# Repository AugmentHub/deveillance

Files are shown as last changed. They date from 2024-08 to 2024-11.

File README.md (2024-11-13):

# Deveillance Devices
We started this project as we have seen an increase in potentially privacy invading devices, such as wearable AI necklace, AR glasses that can take pictures of you, and more. Throughout the 2024 Augmentation Residency, we - Aida Baradari, Treyden Chiaravalloti, and Nasibe Nur Dundar - were thinking about ways of building what we coin "deveillance" technologies. 

**Deveillance** means off-watching, and we define deveillance technologies as technologies that give the power to the individual as to what data is collected and what is not collected. This can take the form of digital data and data potentially collected in the real world. This is, fundamentally, to build the use of these technologies for good and protective measures rather than for malicious intentions. 

There is still a lot of work to be done and we need more engineers tackling the problems of data collection in all realms. We started with Audio but this is a hub for everyone to contribute to a better design of deveillance devices. 

## Audio
Audio Jammers have existed for a while now but has been increasingly difficult to find affordable ones or even good, structured tutorials of how to make your own. This is how we built an audio jammer and how this works.

We are using a motor driver - more specifically the H-Bridge - L298N in order to generate a square wave signal. We formally tried using a signal generator with an amplifier but found it more difficult to get a non-noisy signal. 
The generated square-wave signal is based on the input voltage, for which you can use a power supply for now but we will eventually add batteries that are high enough (to get a good power output, we are currently using the H-Bridge that go up to 30V and 2A) but when we make it more wearable and you want to use it on your shelf, you may want to use a DC-DC Converter, upping the voltage of a generic LiPo battery. 

We are explaining how the Physics behind this works and then also how to make it yourself. 

### Wait, but why does it work? 
In a very simple way of explaining, without needing much physics background: Microphones have diaphragms. When sound hits that diaphragm, it vibrates it, and that movement creates electrical signals (in an abstract way of explaining it). 
Now, sound has different frequencies. We can hear a certain range of frequencies (20Hz to 20kHz) but below or higher than that humans can generally not hear. If you are close enough to our hearing frequency, however, the diaphragm of the microphone can sometimes pick it up. 
And because of this, your voice will be overridden. It cannot be filtered out. 

### Make It Yourself
- [Transducers](https://en.wikipedia.org/wiki/Transducer): For the bigger version, we are currently using the [2223-CUSA-T601-150-2400-TH-ND](https://www.digikey.com/en/products/detail/same-sky-formerly-cui-devices/CUSA-T601-150-2400-TH/16579211). 
- Arduino Nano (or any other Arduino / microcontroller device)

**Putting Things Together**
Here is how we are currently wiring things together (though the topology is very likely to change) :
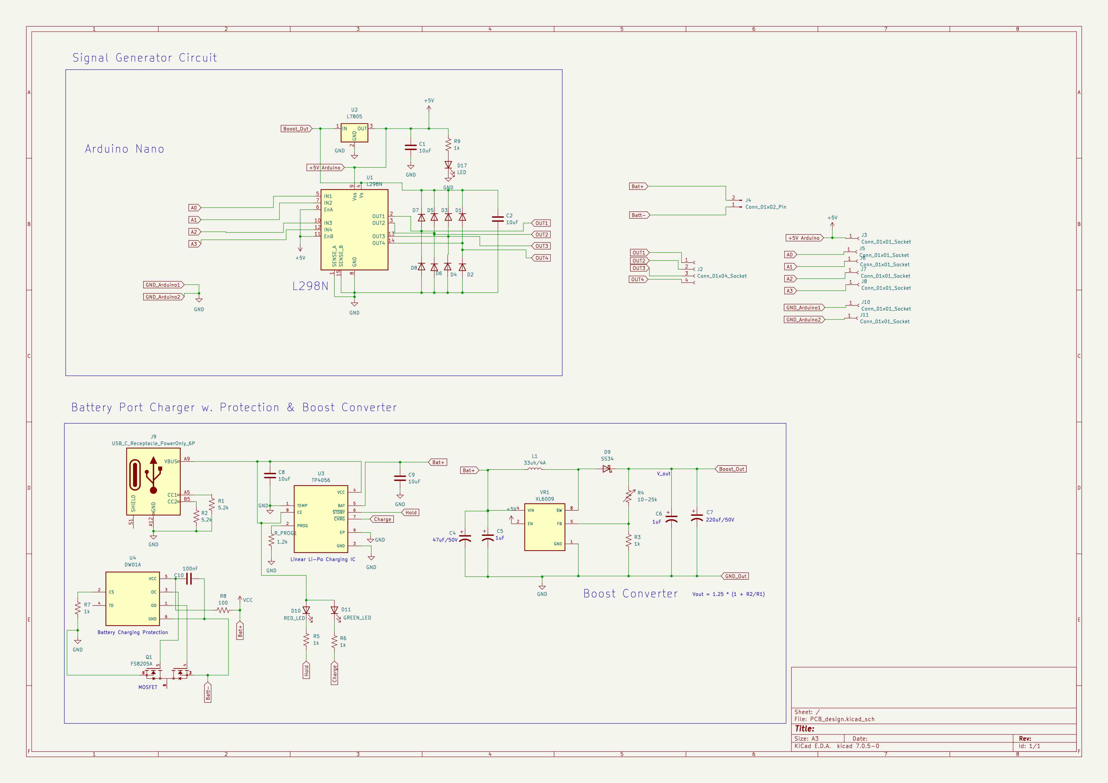
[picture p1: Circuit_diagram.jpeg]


### PCB Design 
Within this directory you will also find a PCB design with the L298N chip on board, battery charging circuit and more included. 
The data parts we are using are the following: 

- TP4056: 1A Standalone Linear Li-Ion Battery Charger with Thermal Regulation. This is for charging our battery and is connected to a USB port. You can find the datasheet [here](https://dlnmh9ip6v2uc.cloudfront.net/datasheets/Prototyping/TP4056.pdf). 
- DW01A: this is a battery protection IC. You can read more about it [here](https://hmsemi.com/downfile/dw01a.pdf)
- XL6009: this is our boost converter IC, which has a wide bandwidth. Find more information [here](https://www.haoyuelectronics.com/Attachment/XL6009/XL6009-DC-DC-Converter-Datasheet.pdf).
- L298N: this is our Hbridge to create our Ultrasonic wave.

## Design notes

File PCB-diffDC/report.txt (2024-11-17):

Info: Placement file: '/Users/aida/Desktop/deveillance/PCB_design/PCB_design-all-pos.csv'.
Info: Component count: 41.
Info: File generation successful.

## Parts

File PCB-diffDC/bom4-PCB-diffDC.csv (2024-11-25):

Id | Designator | Footprint | Quantity | Designation | Supplier and ref
1 | C4 | CP_Elec_6.3x7.7 | 1 | 47uF/50V
2 | L1 | L_6.3x6.3_H3 | 1 | 22uh/2A
3 | D17 | LED_0603_1608Metric_Pad1.05x0.95mm_HandSolder | 1 | LED
4 | U5 | SOT-23-6 | 1 | MT3608
5 | R9,R5,R3,R6,R7 | R_0603_1608Metric_Pad0.98x0.95mm_HandSolder | 5 | 1k
6 | C7 | CAP-SMD_BD10.0-L10.3-W10.3-FD | 1 | 220uF/50V
7 | D6,D2,D8,D3,D7,D4,D1,D5 | D_0805_2012Metric_Pad1.15x1.40mm_HandSolder | 8 | 1N5400
8 | J10,J6,J3,J11,J8,J7,J5 | TestPoint_THTPad_1.0x1.0mm_Drill0.5mm | 7 | Conn_01x01_Socket
9 | R2,R1 | R_0603_1608Metric_Pad0.98x0.95mm_HandSolder | 2 | 5.2k
10 | C9,C8,C2,C1 | C_0603_1608Metric_Pad1.08x0.95mm_HandSolder | 4 | 10uF
11 | U2 | VREG_L78M05CDT | 1 | L7805
12 | J9 | USB_C_Receptacle_GCT_USB4135-GF-A_6P_TopMnt_Horizontal | 1 | USB_C_Receptacle_PowerOnly_6P
13 | R8 | R_0603_1608Metric_Pad0.98x0.95mm_HandSolder | 1 | 100
14 | D9 | DIOM8059X256N | 1 | SS34
15 | D10 | LED_0201_0603Metric_Pad0.64x0.40mm_HandSolder | 1 | RED_LED
16 | J2 | PinHeader_1x04_P1.00mm_Vertical | 1 | Conn_01x04_Socket
17 | Q2 | SOT95P280X145-6N | 1 | FS8205
18 | U1 | TO127P2020X500X2100-15 | 1 | L298N
19 | J4 | JST_EH_S2B-EH_1x02_P2.50mm_Horizontal | 1 | Conn_01x02_Pin
20 | R_PROG1 | R_0603_1608Metric_Pad0.98x0.95mm_HandSolder | 1 | 1.2k
21 | C5,C6 | C_0603_1608Metric_Pad1.08x0.95mm_HandSolder | 2 | 1uF
22 | SW1 | SW_MINI-SPDT-SW | 1 | SW_SPDT
23 | U4 | SOT95P280X145-6N | 1 | DW01A
24 | D11 | LED_0201_0603Metric_Pad0.64x0.40mm_HandSolder | 1 | GREEN_LED
25 | R4 | Potentiometer_Bourns_3224X_Vertical | 1 | 20k-40k
26 | C10 | C_0603_1608Metric_Pad1.08x0.95mm_HandSolder | 1 | 100nF
27 | U3 | SOP127P600X175-9N | 1 | TP4056

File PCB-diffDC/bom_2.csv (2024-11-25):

Comment | Designator | Footprint
1N5400 | D5,D8,D7,D6,D4,D3,D2 | D_0805_2012Metric_Pad1.15x1.40mm_HandSolder
1uF | C5 | C_0201_0603Metric_Pad0.64x0.40mm_HandSolder
L7805 | U2 | VREG_L78M05CDT
Conn_01x01_Socket | J3,J10,J11,J6,J5,J7,J8 | TestPoint_THTPad_1.0x1.0mm_Drill0.5mm
10uF | C9,C2,C8,C1 | C_0603_1608Metric_Pad1.08x0.95mm_HandSolder
1k | R6,R3,R9,R7,R5 | R_0603_1608Metric_Pad0.98x0.95mm_HandSolder
USB_C_Receptacle_PowerOnly_6P | J9 | USB_C_Receptacle_GCT_USB4135-GF-A_6P_TopMnt_Horizontal
5.2k | R1,R2 | R_0603_1608Metric_Pad0.98x0.95mm_HandSolder
L298N | U1 | TO127P2020X500X2100-15
47uF/50V | C4 | CAPAE1050X1050N
Conn_01x04_Socket | J2 | PinHeader_1x04_P1.00mm_Vertical
RED_LED | D10 | LED_0201_0603Metric_Pad0.64x0.40mm_HandSolder
XL6009 | VR1 | DPAK170P1435X465-6N
SS34 | D9 | DIOM8059X256N
100 | R8 | R_0603_1608Metric_Pad0.98x0.95mm_HandSolder
FS8205A | Q1 | SOP65P640X120-8N
220uF/50V | C7 | CAPAE1050X1050N
Conn_01x02_Pin | J4 | JST_EH_S2B-EH_1x02_P2.50mm_Horizontal
33uh/4A | L1 | L_7.3x7.3_H3.5
TP4056 | U3 | SOP127P600X175-9N
1.2k | R_PROG1 | R_0603_1608Metric_Pad0.98x0.95mm_HandSolder
10-25k | R4 | Potentiometer_Bourns_3224X_Vertical
GREEN_LED | D11 | LED_0201_0603Metric_Pad0.64x0.40mm_HandSolder
DW01A | U4 | SOT95P280X145-6N
LED | D17 | LED_0201_0603Metric_Pad0.64x0.40mm_HandSolder
100nF | C10 | C_0603_1608Metric_Pad1.08x0.95mm_HandSolder
1uF | C6 | C_0603_1608Metric_Pad1.08x0.95mm_HandSolder
1N5400 | D1 | D_0805_2012Metric_Pad1.15x1.40mm_HandSolder

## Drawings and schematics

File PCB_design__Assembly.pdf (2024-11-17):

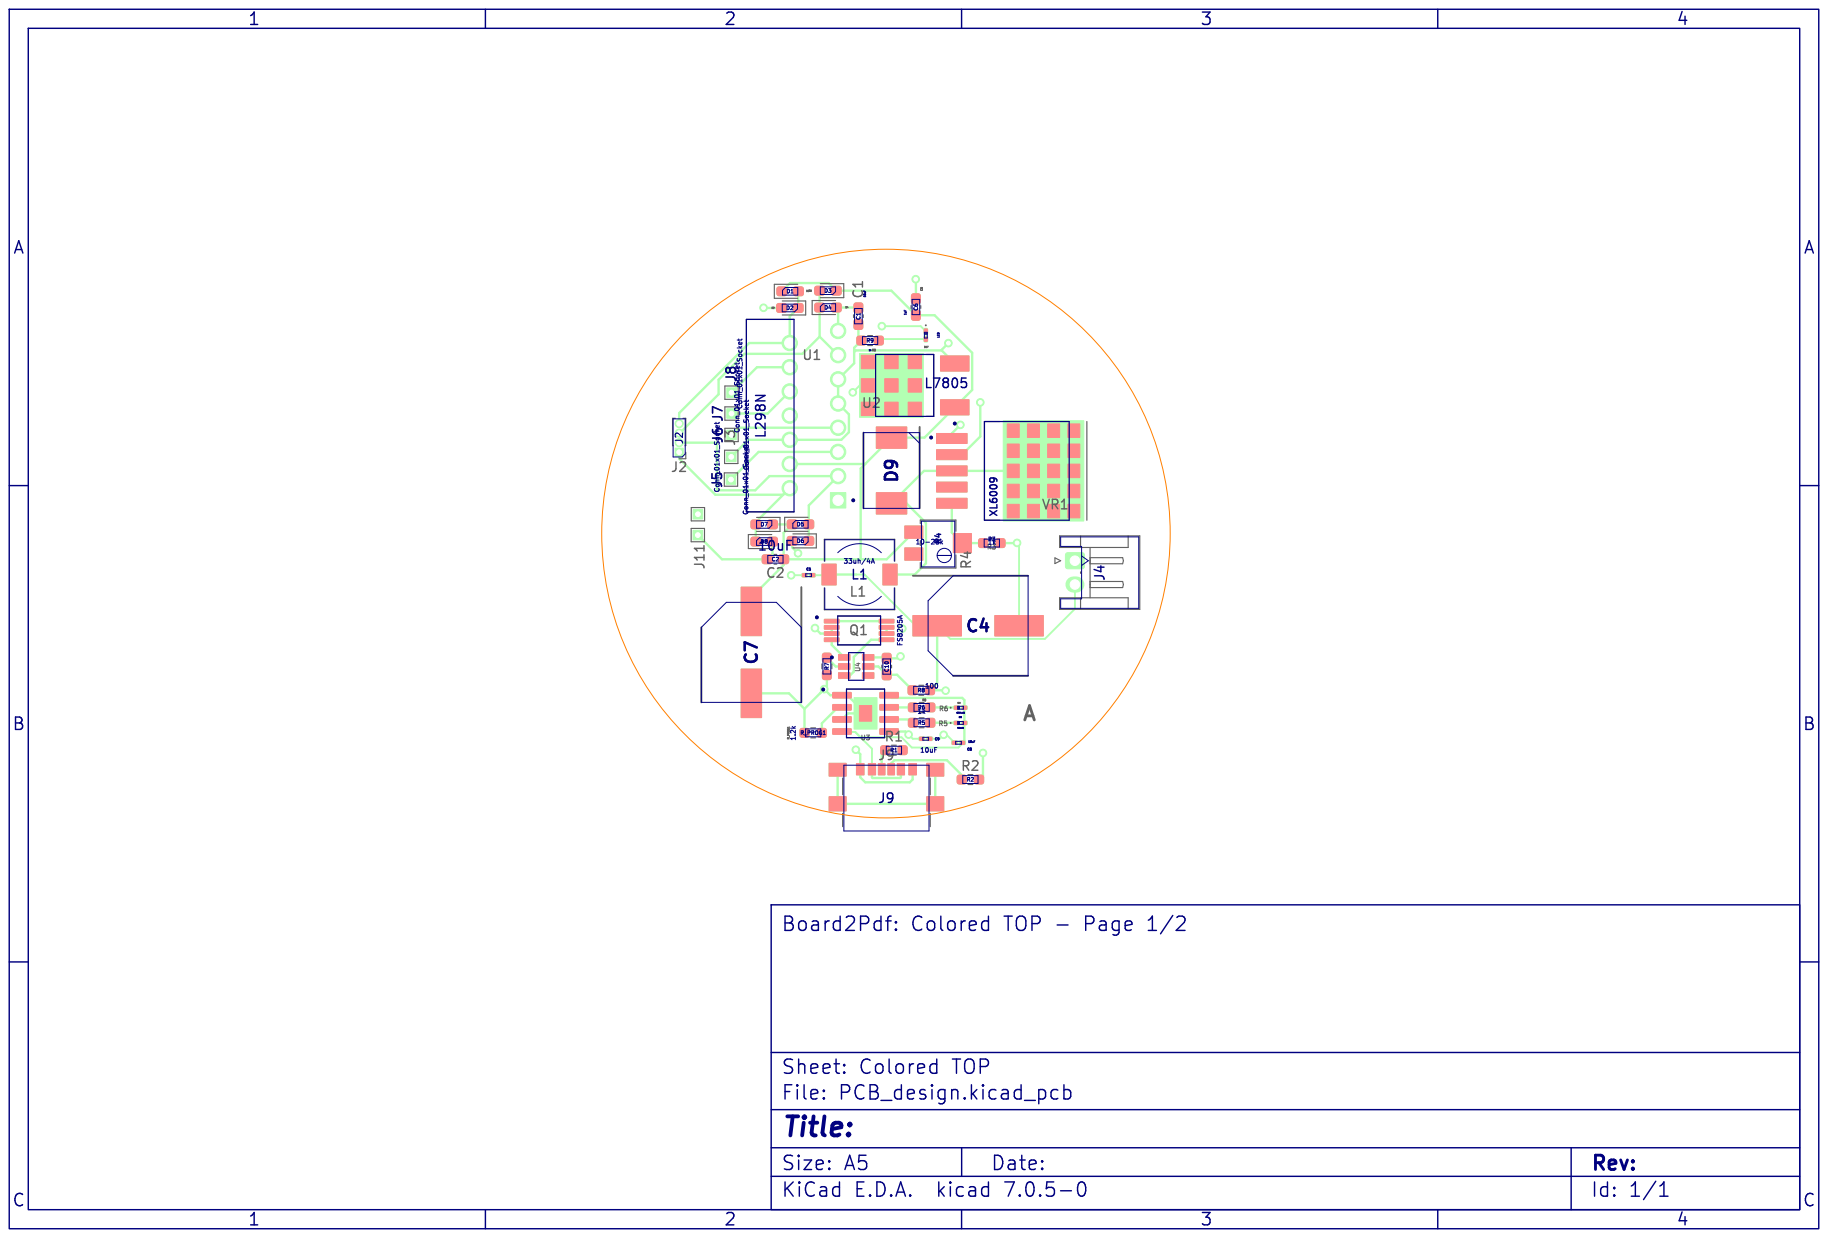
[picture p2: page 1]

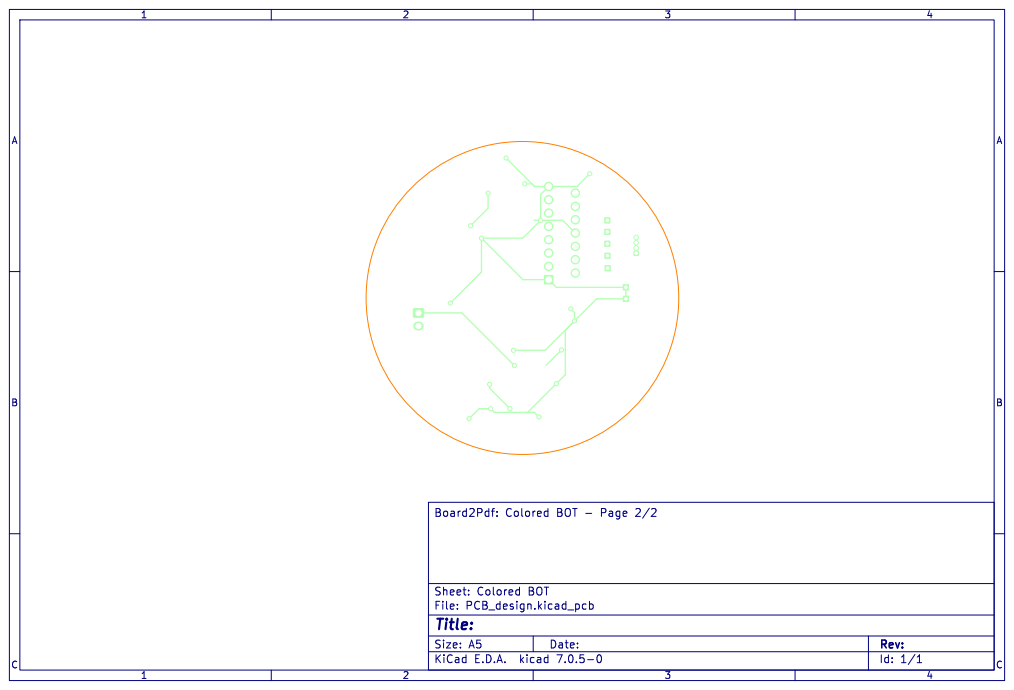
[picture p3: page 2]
BC Date: KiCad; kicad; 7.0.5-0 Size: A5; Rev:; Id: 1/1 Title: File: PCB_design.kicad_pcb Sheet: Colored; BOT Board2Pdf:; Colored; BOT -; Page 2/2

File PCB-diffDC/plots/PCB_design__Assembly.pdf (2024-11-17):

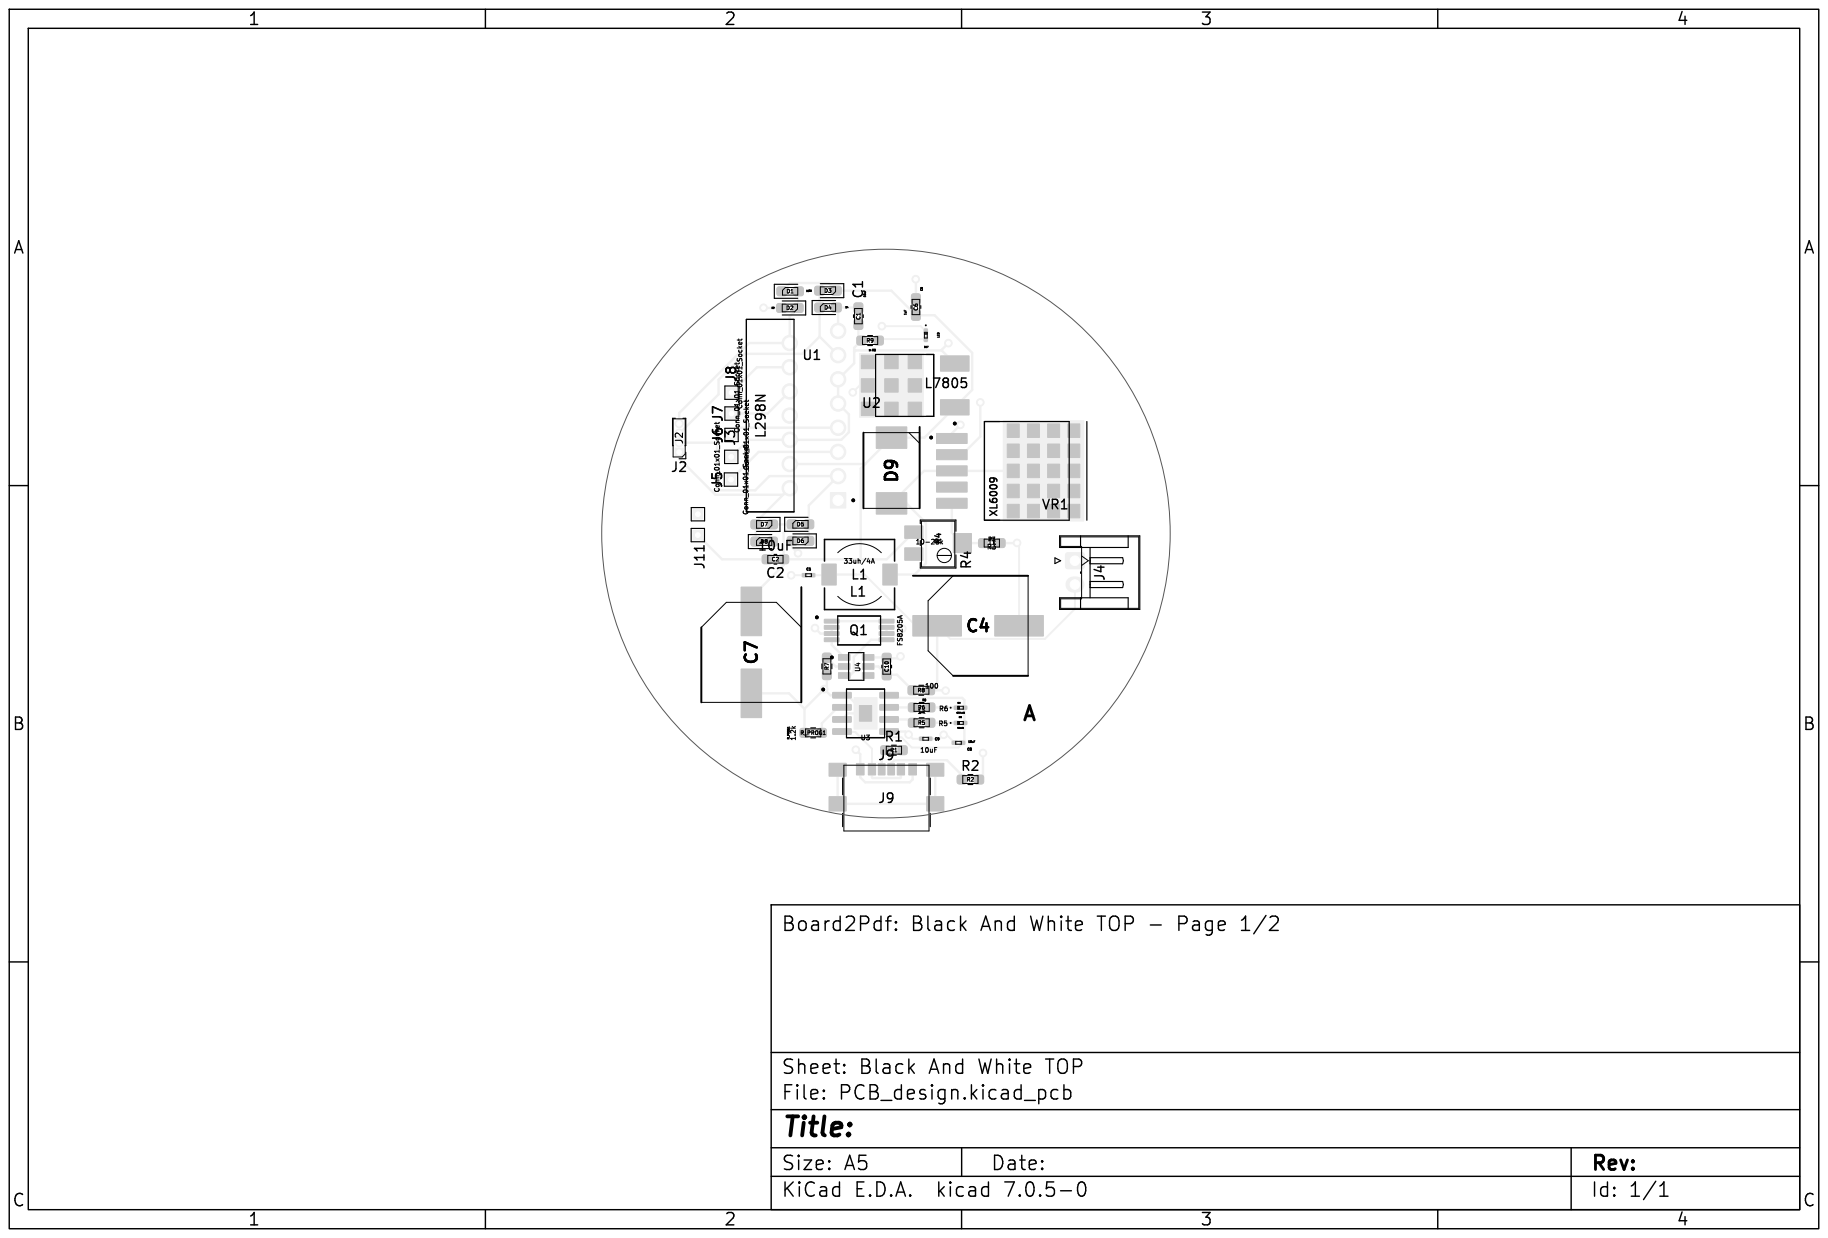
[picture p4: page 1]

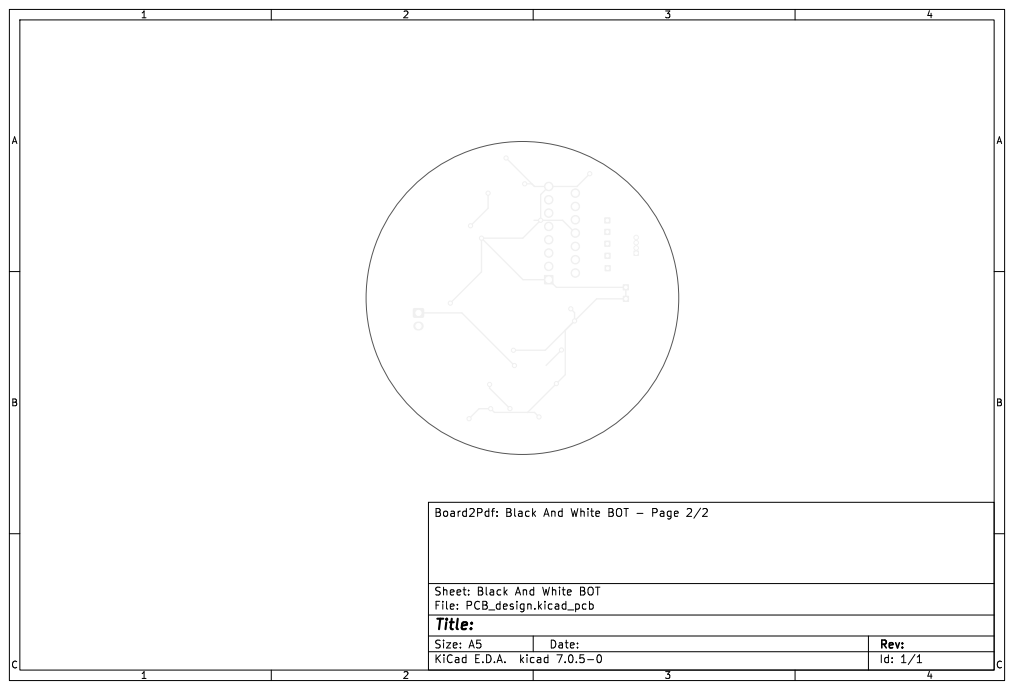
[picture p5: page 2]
BC Date: KiCad; kicad; 7.0.5-0 Size: A5; Rev:; Id: 1/1 Title: File: PCB_design.kicad_pcb Sheet:; Black; And; White; BOT Board2Pdf:; BOT -; Page 2/2

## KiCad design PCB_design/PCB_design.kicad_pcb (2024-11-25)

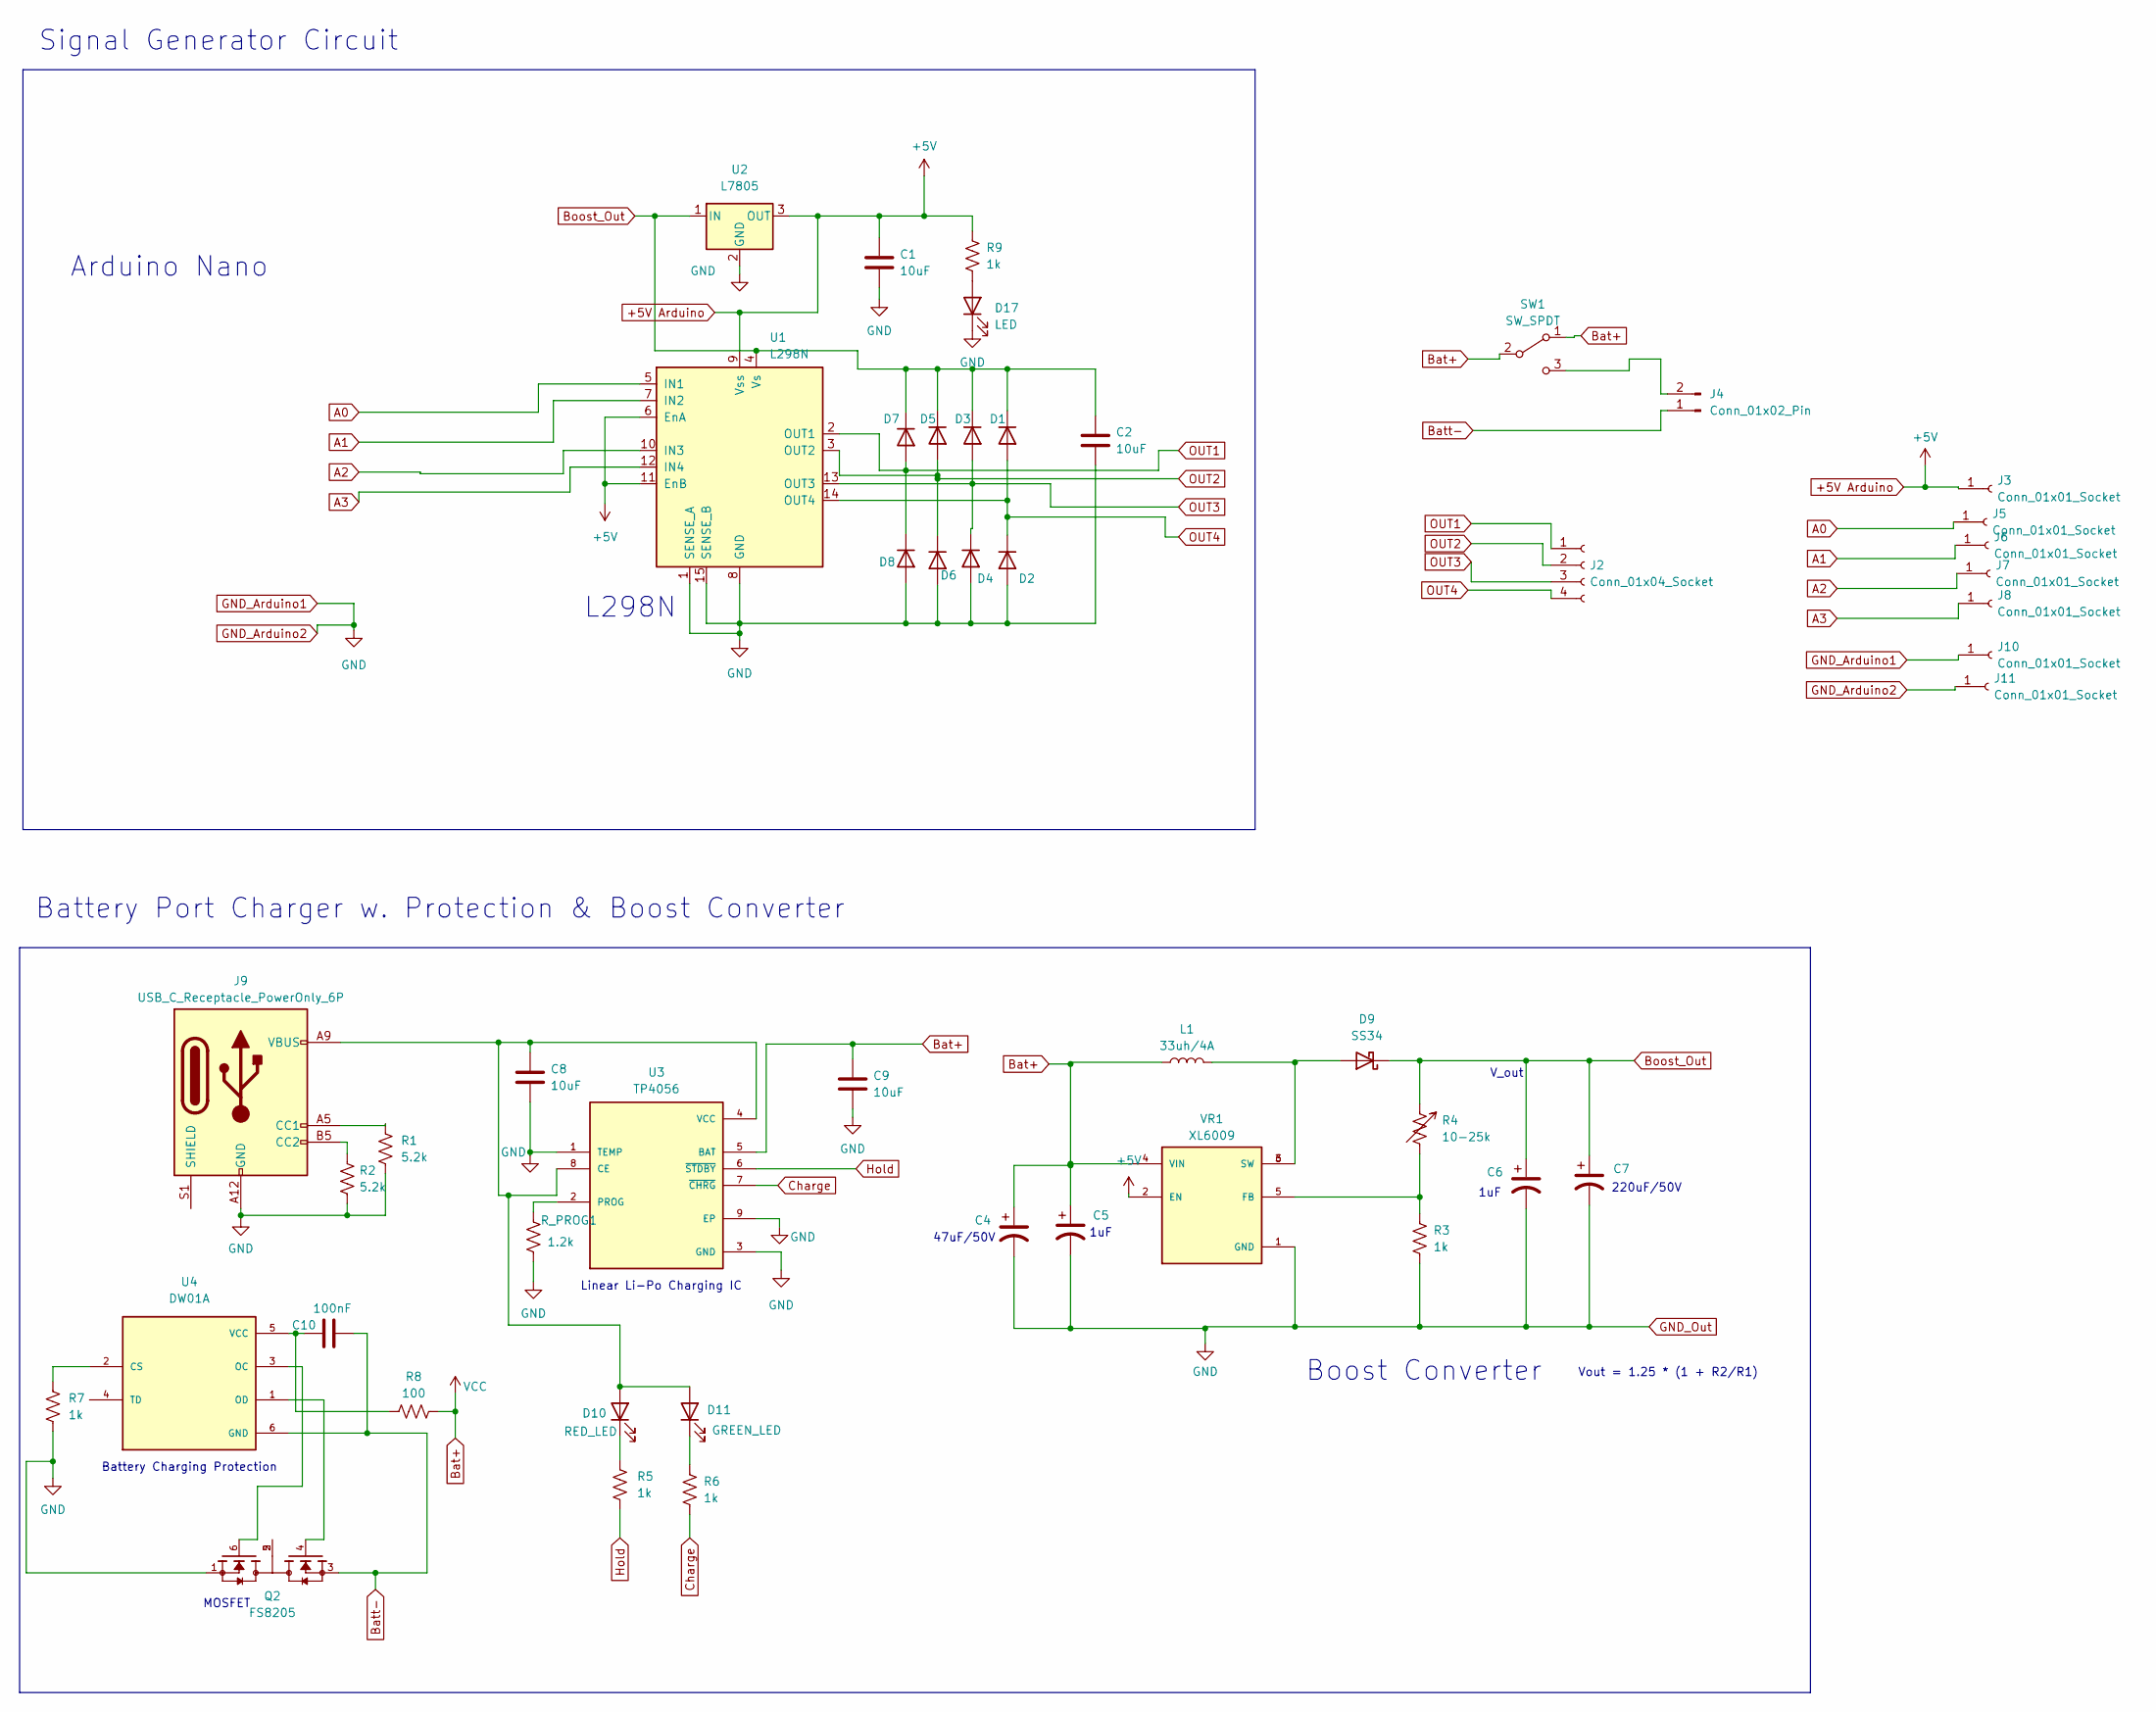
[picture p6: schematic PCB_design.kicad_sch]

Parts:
C1, C2, C8, C9: 10uF; C_0603_1608Metric_Pad1.08x0.95mm_HandSolder
C4: 47uF/50V; CP_Elec_6.3x7.7
C5, C6: 1uF; C_0603_1608Metric_Pad1.08x0.95mm_HandSolder
C7: 220uF/50V; CAP-SMD_BD10.0-L10.3-W10.3-FD
C10: 100nF; C_0603_1608Metric_Pad1.08x0.95mm_HandSolder
D1, D2, D3, D4, D5, D6, D7, D8: 1N5400; D_0805_2012Metric_Pad1.15x1.40mm_HandSolder
D9: SS34; DIOM8059X256N
D10: RED_LED; LED_0201_0603Metric_Pad0.64x0.40mm_HandSolder
D11: GREEN_LED; LED_0201_0603Metric_Pad0.64x0.40mm_HandSolder
D17: LED; LED_0201_0603Metric_Pad0.64x0.40mm_HandSolder
J2: Conn_01x04_Socket; PinHeader_1x04_P1.00mm_Vertical
J3, J5, J6, J7, J8, J10, J11: Conn_01x01_Socket; TestPoint_THTPad_1.0x1.0mm_Drill0.5mm
J4: Conn_01x02_Pin; JST_EH_S2B-EH_1x02_P2.50mm_Horizontal
J9: USB_C_Receptacle_PowerOnly_6P; USB_C_Receptacle_GCT_USB4135-GF-A_6P_TopMnt_Horizontal
L1: 33uh/4A; ND-SMD_L11.6-W10.1_final_13mm
Q2: FS8205; SOT95P280X145-6N; PARTREV 1.9
R1, R2: 5.2k; R_0603_1608Metric_Pad0.98x0.95mm_HandSolder
R3, R5, R6, R7, R9: 1k; R_0603_1608Metric_Pad0.98x0.95mm_HandSolder
R4: 10-25k; Potentiometer_Bourns_3224X_Vertical
R8: 100; R_0603_1608Metric_Pad0.98x0.95mm_HandSolder
R_PROG1: 1.2k; R_0603_1608Metric_Pad0.98x0.95mm_HandSolder
SW1: SW_SPDT; SW_MINI-SPDT-SW
U1: L298N; TO127P2020X500X2100-15
U2: L7805; VREG_L78M05CDT
U3: TP4056; SOP127P600X175-9N
U4: DW01A; SOT95P280X145-6N; PARTREV 1.8
VR1: XL6009; DPAK170P1435X465-6N; PARTREV 1.1

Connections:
+5V Arduino: C1.1, J3.1, R9.1, U1.6 (EnA), U1.9 (Vss), U1.11 (EnB), U2.3 (OUT), VR1.2 (EN)
A0: J5.1, U1.5 (IN1)
A1: J6.1, U1.7 (IN2)
A2: J7.1, U1.10 (IN3)
A3: J8.1, U1.12 (IN4)
Bat+: C4.1, C5.1, C9.1, L1.1, R8.2, SW1.1 (A), SW1.2 (B), U3.5 (BAT), VR1.4 (VIN)
Batt-: C10.2, J4.1, Q2.3, U4.6 (GND)
Boost_Out: C2.1, C6.1, C7.1, D1.1 (K), D3.1 (K), D5.1 (K), D7.1 (K), D9.1 (A), R4.1, U1.4 (Vs), U2.1 (IN)
Charge: R6.2, U3.7 (~CHRG)
GND_Arduino1: C1.2, C2.2, C4.2, C5.2, C6.2, C7.2, C8.2, C9.2, D2.2 (A), D4.2 (A), D6.2 (A), D8.2 (A), D17.1 (K), J9.A12 (GND), J9.B12 (GND), J10.1, J11.1, Q2.1, R1.2, R2.2, R3.2, R7.2, R_PROG1.2, U1.1 (SENSE_A), U1.8 (GND), U1.15 (SENSE_B), U2.2 (GND), U3.1 (TEMP), U3.3 (GND), U3.9 (EP), VR1.1 (GND)
Hold: R5.2, U3.6 (~STDBY)
unnamed: D9.2 (B), L1.2, VR1.3 (SW), VR1.6 (SW)
unnamed: C8.1, D10.2 (A), D11.2 (A), J9.A9 (VBUS), J9.B9 (VBUS), U3.4 (VCC), U3.8 (CE)
unnamed: D10.1 (K), R5.1
unnamed: D11.1 (K), R6.1
unnamed: D17.2 (A), R9.2
unnamed: J4.2, SW1.3 (C)
unnamed: J9.A5 (CC1), R1.1
unnamed: J9.B5 (CC2), R2.1
unnamed: Q2.2, Q2.5
unnamed: R_PROG1.1, U3.2 (PROG)
unnamed: R7.1, U4.2 (CS)
unnamed: Q2.6, U4.3 (OC)
unnamed: Q2.4, U4.1 (OD)
unnamed: C10.1, R8.1, U4.5 (VCC)
unnamed: R3.1, R4.2, VR1.5 (FB)
OUT1: D7.2 (A), D8.1 (K), J2.1, U1.2 (OUT1)
OUT2: D5.2 (A), D6.1 (K), J2.2, U1.3 (OUT2)
OUT3: D3.2 (A), D4.1 (K), J2.3, U1.13 (OUT3)
OUT4: D1.2 (A), D2.1 (K), J2.4, U1.14 (OUT4)

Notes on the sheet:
Battery Charging Protection
Signal Generator Circuit
1uF
L298N
Battery Port Charger w. Protection & Boost Converter
MOSFET
Vout = 1.25 * (1 + R2/R1)
47uF/50V
V_out
Boost Converter
Linear Li-Po Charging IC
220uF/50V
Arduino Nano

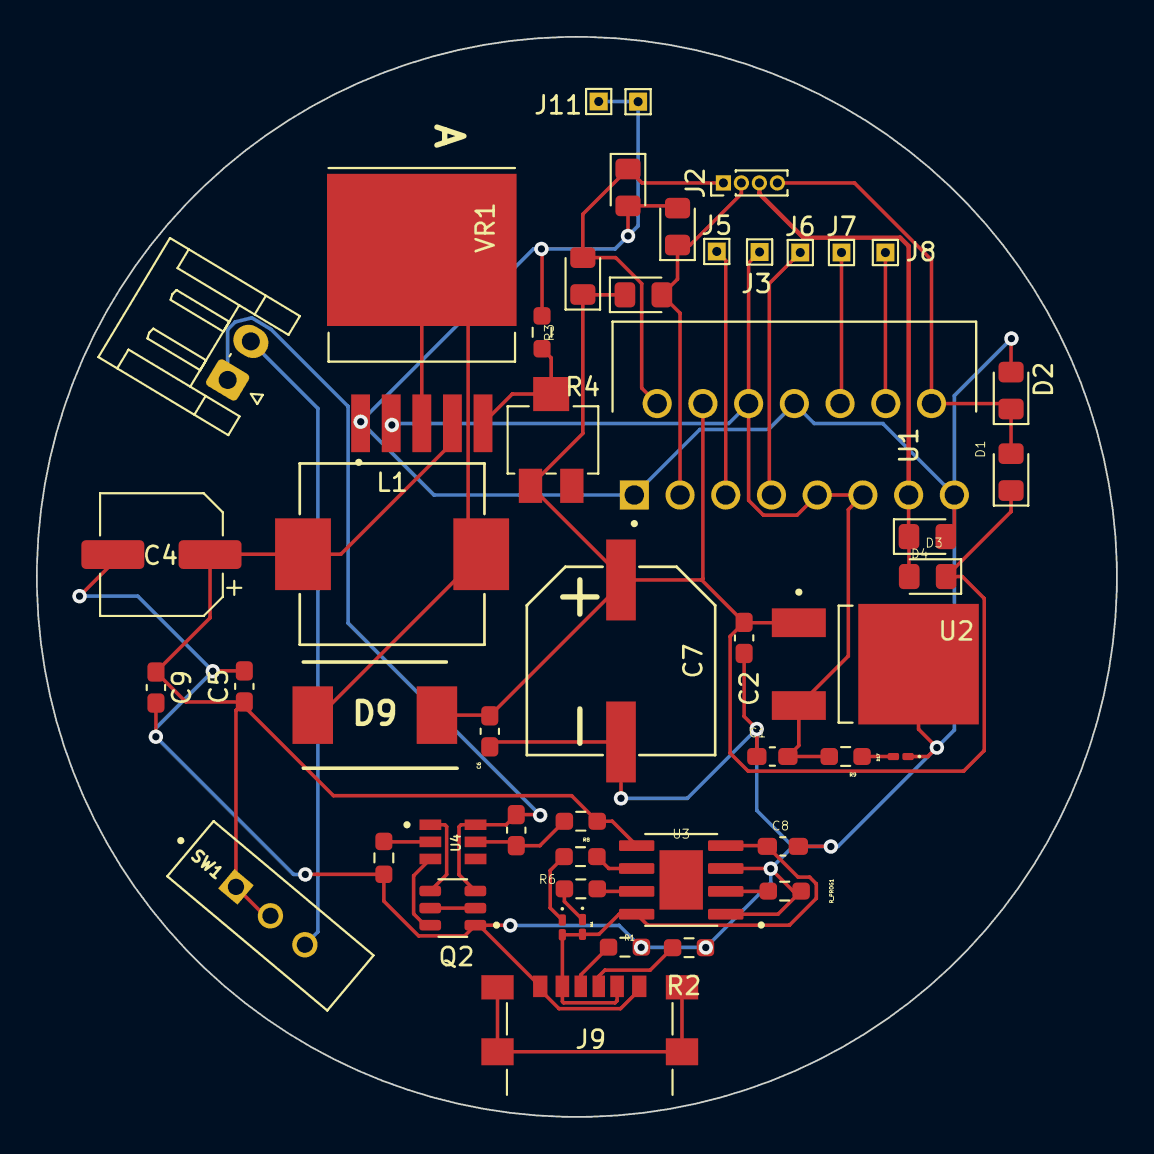
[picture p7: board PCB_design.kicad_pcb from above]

Board: 2 copper layers, 60.0 x 60.0 mm, 49 parts (0 on the bottom side), 30 nets.

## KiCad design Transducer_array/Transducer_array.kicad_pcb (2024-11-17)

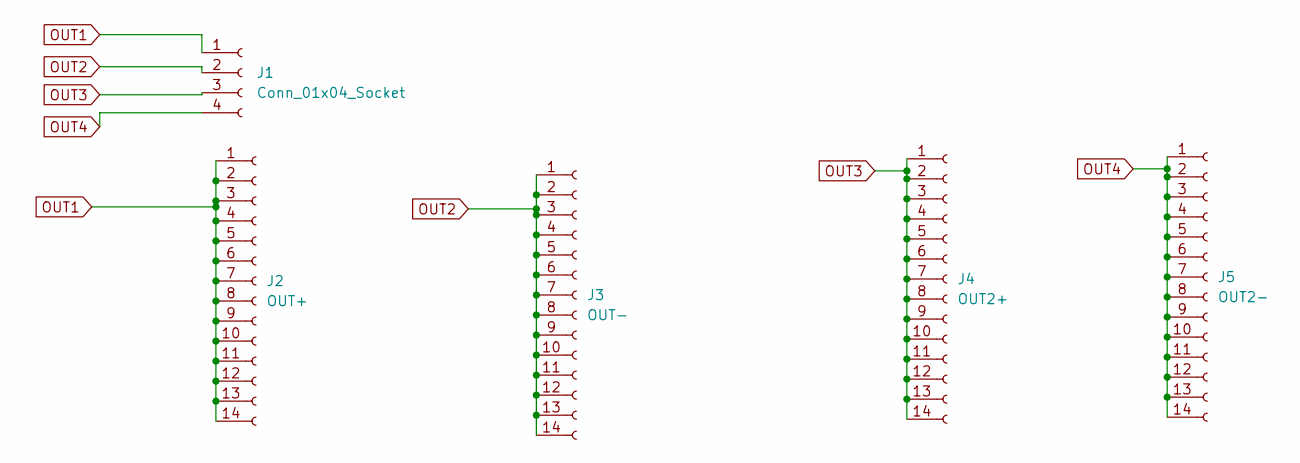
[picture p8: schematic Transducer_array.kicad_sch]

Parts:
J1: Conn_01x04_Socket; PinSocket_1x04_P1.00mm_Vertical
J2: OUT+; PinSocket_1x14_P1.00mm_Vertical
J3: OUT-; PinSocket_1x14_P1.00mm_Vertical
J4: OUT2+; PinSocket_1x14_P1.00mm_Vertical
J5: OUT2-; PinSocket_1x14_P1.00mm_Vertical

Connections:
OUT1: J1.1, J2.1, J2.2, J2.3, J2.4, J2.5, J2.6, J2.7, J2.8, J2.9, J2.10, J2.11, J2.12, J2.13, J2.14
OUT2: J1.2, J3.1, J3.2, J3.3, J3.4, J3.5, J3.6, J3.7, J3.8, J3.9, J3.10, J3.11, J3.12, J3.13, J3.14
OUT3: J1.3, J4.1, J4.2, J4.3, J4.4, J4.5, J4.6, J4.7, J4.8, J4.9, J4.10, J4.11, J4.12, J4.13, J4.14
OUT4: J1.4, J5.1, J5.2, J5.3, J5.4, J5.5, J5.6, J5.7, J5.8, J5.9, J5.10, J5.11, J5.12, J5.13, J5.14

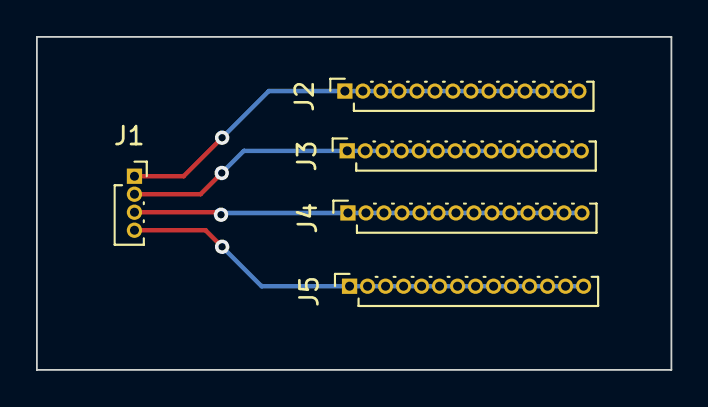
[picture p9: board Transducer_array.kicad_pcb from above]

Board: 2 copper layers, 35.2 x 18.5 mm, 5 parts (0 on the bottom side), 4 nets.

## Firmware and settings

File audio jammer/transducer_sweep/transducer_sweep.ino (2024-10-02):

#include <avr/sleep.h>
#include <avr/power.h>

#define N_PORTS 1 // number of ports being used. 
#define N_DIVS 24 // number of steps in waveform

#define WAIT_LOT(a) __asm__ __volatile__ ("nop"); __asm__ __volatile__ ("nop"); __asm__ __volatile__ ("nop");  __asm__ __volatile__ ("nop"); __asm__ __volatile__ ("nop");__asm__ __volatile__ ("nop"); __asm__ __volatile__ ("nop");__asm__ __volatile__ ("nop"); __asm__ __volatile__ ("nop");  __asm__ __volatile__ ("nop"); __asm__ __volatile__ ("nop");__asm__ __volatile__ ("nop");  __asm__ __volatile__ ("nop");  __asm__ __volatile__ ("nop")
#define WAIT_MID(a) __asm__ __volatile__ ("nop"); __asm__ __volatile__ ("nop"); __asm__ __volatile__ ("nop");  __asm__ __volatile__ ("nop"); __asm__ __volatile__ ("nop");__asm__ __volatile__ ("nop"); __asm__ __volatile__ ("nop");__asm__ __volatile__ ("nop"); __asm__ __volatile__ ("nop"); __asm__ __volatile__ ("nop"); __asm__ __volatile__ ("nop"); __asm__ __volatile__ ("nop"); __asm__ __volatile__ ("nop")
#define WAIT_LIT(a) __asm__ __volatile__ ("nop"); __asm__ __volatile__ ("nop"); __asm__ __volatile__ ("nop");  __asm__ __volatile__ ("nop"); __asm__ __volatile__ ("nop");  __asm__ __volatile__ ("nop");  __asm__ __volatile__ ("nop");  __asm__ __volatile__ ("nop");  __asm__ __volatile__ ("nop")

// Defining where to output our wave

#define OUTPUT_WAVE(pointer, d)  PORTC = pointer[d*N_PORTS + 0]

//half a second
#define STEP_SIZE 1
#define BUTTON_SENS 2500 
#define N_FRAMES 24 // number of steps in waveform

static byte frame = 0;
// SETTING THIS FOR THE ANIMATION (WAVEFORM)

static byte animation[N_FRAMES][N_DIVS] = 
{{0x5,0x5,0x5,0x5,0x5,0x5,0x5,0x5,0x5,0x5,0x5,0x5,0xa,0xa,0xa,0xa,0xa,0xa,0xa,0xa,0xa,0xa,0xa,0xa},
{0x9,0x5,0x5,0x5,0x5,0x5,0x5,0x5,0x5,0x5,0x5,0x5,0x6,0xa,0xa,0xa,0xa,0xa,0xa,0xa,0xa,0xa,0xa,0xa},
{0x9,0x9,0x5,0x5,0x5,0x5,0x5,0x5,0x5,0x5,0x5,0x5,0x6,0x6,0xa,0xa,0xa,0xa,0xa,0xa,0xa,0xa,0xa,0xa},
{0x9,0x9,0x9,0x5,0x5,0x5,0x5,0x5,0x5,0x5,0x5,0x5,0x6,0x6,0x6,0xa,0xa,0xa,0xa,0xa,0xa,0xa,0xa,0xa},
{0x9,0x9,0x9,0x9,0x5,0x5,0x5,0x5,0x5,0x5,0x5,0x5,0x6,0x6,0x6,0x6,0xa,0xa,0xa,0xa,0xa,0xa,0xa,0xa},
{0x9,0x9,0x9,0x9,0x9,0x5,0x5,0x5,0x5,0x5,0x5,0x5,0x6,0x6,0x6,0x6,0x6,0xa,0xa,0xa,0xa,0xa,0xa,0xa},
{0x9,0x9,0x9,0x9,0x9,0x9,0x5,0x5,0x5,0x5,0x5,0x5,0x6,0x6,0x6,0x6,0x6,0x6,0xa,0xa,0xa,0xa,0xa,0xa},
{0x9,0x9,0x9,0x9,0x9,0x9,0x9,0x5,0x5,0x5,0x5,0x5,0x6,0x6,0x6,0x6,0x6,0x6,0x6,0xa,0xa,0xa,0xa,0xa},
{0x9,0x9,0x9,0x9,0x9,0x9,0x9,0x9,0x5,0x5,0x5,0x5,0x6,0x6,0x6,0x6,0x6,0x6,0x6,0x6,0xa,0xa,0xa,0xa},
{0x9,0x9,0x9,0x9,0x9,0x9,0x9,0x9,0x9,0x5,0x5,0x5,0x6,0x6,0x6,0x6,0x6,0x6,0x6,0x6,0x6,0xa,0xa,0xa},
{0x9,0x9,0x9,0x9,0x9,0x9,0x9,0x9,0x9,0x9,0x5,0x5,0x6,0x6,0x6,0x6,0x6,0x6,0x6,0x6,0x6,0x6,0xa,0xa},
{0x9,0x9,0x9,0x9,0x9,0x9,0x9,0x9,0x9,0x9,0x9,0x5,0x6,0x6,0x6,0x6,0x6,0x6,0x6,0x6,0x6,0x6,0x6,0xa},
{0x9,0x9,0x9,0x9,0x9,0x9,0x9,0x9,0x9,0x9,0x9,0x9,0x6,0x6,0x6,0x6,0x6,0x6,0x6,0x6,0x6,0x6,0x6,0x6},
{0x5,0x9,0x9,0x9,0x9,0x9,0x9,0x9,0x9,0x9,0x9,0x9,0xa,0x6,0x6,0x6,0x6,0x6,0x6,0x6,0x6,0x6,0x6,0x6},
{0x5,0x5,0x9,0x9,0x9,0x9,0x9,0x9,0x9,0x9,0x9,0x9,0xa,0xa,0x6,0x6,0x6,0x6,0x6,0x6,0x6,0x6,0x6,0x6},
{0x5,0x5,0x5,0x9,0x9,0x9,0x9,0x9,0x9,0x9,0x9,0x9,0xa,0xa,0xa,0x6,0x6,0x6,0x6,0x6,0x6,0x6,0x6,0x6},
{0x5,0x5,0x5,0x5,0x9,0x9,0x9,0x9,0x9,0x9,0x9,0x9,0xa,0xa,0xa,0xa,0x6,0x6,0x6,0x6,0x6,0x6,0x6,0x6},
{0x5,0x5,0x5,0x5,0x5,0x9,0x9,0x9,0x9,0x9,0x9,0x9,0xa,0xa,0xa,0xa,0xa,0x6,0x6,0x6,0x6,0x6,0x6,0x6},
{0x5,0x5,0x5,0x5,0x5,0x5,0x9,0x9,0x9,0x9,0x9,0x9,0xa,0xa,0xa,0xa,0xa,0xa,0x6,0x6,0x6,0x6,0x6,0x6},
{0x5,0x5,0x5,0x5,0x5,0x5,0x5,0x9,0x9,0x9,0x9,0x9,0xa,0xa,0xa,0xa,0xa,0xa,0xa,0x6,0x6,0x6,0x6,0x6},
{0x5,0x5,0x5,0x5,0x5,0x5,0x5,0x5,0x9,0x9,0x9,0x9,0xa,0xa,0xa,0xa,0xa,0xa,0xa,0xa,0x6,0x6,0x6,0x6},
{0x5,0x5,0x5,0x5,0x5,0x5,0x5,0x5,0x5,0x9,0x9,0x9,0xa,0xa,0xa,0xa,0xa,0xa,0xa,0xa,0xa,0x6,0x6,0x6},
{0x5,0x5,0x5,0x5,0x5,0x5,0x5,0x5,0x5,0x5,0x9,0x9,0xa,0xa,0xa,0xa,0xa,0xa,0xa,0xa,0xa,0xa,0x6,0x6},
{0x5,0x5,0x5,0x5,0x5,0x5,0x5,0x5,0x5,0x5,0x5,0x9,0xa,0xa,0xa,0xa,0xa,0xa,0xa,0xa,0xa,0xa,0xa,0x6}};


void setup()
{
   DDRC = 0b00001111; //A0 to A3 are the signal outputs
   PORTC = 0b00000000; // Port C initialized to 0
   
   pinMode(10, OUTPUT); //pin 10 (B2) generates a 25 kHz signal to sync 
   pinMode(11, INPUT_PULLUP); //pin 11 (B3) is the sync in
   //please connect pin 10 to pin 11

   for (int i = 2; i < 8; ++i){  //pin 2 to 7 (D2 to D7) are inputs for the buttons
    pinMode(i, INPUT_PULLUP); // setting these pins to be pull-up -> Sets pin to a high voltage level. ACTIVE LOW
   }

  // generate a sync signal of 25khz in pin 10
  noInterrupts();           // we dont' want the code to be interrupted so we are initiating no interrupts here.
  
  /* 
  This register controls the mode of operation and output behavrio fo the timer
  bit (WGM10) | bit (WGM11) => sets the timer to fast PWM mode, meaning that timer countrs from 0 to max and then resets to 0 creating a high-frequency PWM signal
  bit (COM1B1) => configures behavior of the Output Compare pin; 
  */
  TCCR1A = bit (WGM10) | bit (WGM11) | bit (COM1B1); // fast PWM, clear OC1B on compare

  /*
  This register is the timer / counter control register B; it controls the mode of operation and clock source.
  bit (WGM12) | bit (WGM13) continues setting te timer to Fast PWM mode
  bit (CS10) is setting the clock for the timer with no prescaler, meaning the timer runs at full speed.
  */
  TCCR1B = bit (WGM12) | bit (WGM13) | bit (CS10);   // fast PWM, no prescaler
// WHEN USING 40khZ Ultrasonic transducers use this

  // OCR1A =  (F_CPU / 40000L) - 1;
  // OCR1B = (F_CPU / 40000L) / 2;

  /* WHEN USING 25KHZ ULTRASONIC TRANSDUCERS USE THIS
  OCR1A = Output Compare Register A for Timer1
  This register holds the value that the timer countr up to before resetting to 0!
  F_CPU / 40000L - 1 calculate the value for OCR1A
  FCPU is the clock frequency of the Arduino (typically this is 16MHz)
  for 40khz we get OCR1a = 399, so the counter will count up from 0 to 399 creating the PWM signal with a frequency of 40Khz.
  */
  OCR1A =  (F_CPU / 25000L) - 1;

  /*
  OCR1B is the Output Compare Register B for Timer1, this register holds the vlaue at whihc the OC1B pin is cleared. 
  For 50% duty cycle, OCR1B is set to half of OCR1A
  This means that OC1B pin will be set HIGH when the timer starts counting and will be cleared (LOW) when the timer reaches 200 resulting in a 50% duty cycle.
  */

  OCR1B = (F_CPU / 25000L) / 2;
  
  // Renabling this after we have set up the timer configuration
  interrupts();             // enable all interrupts

  /*
  Here, we are disabling unecessary peripherals
  They are not needed because we don't need ADC to send a signal, neither do we need the SPI, I2C protocol, or timer 0
  */
  ADCSRA = 0;  // ADC
  power_adc_disable ();
  power_spi_disable();
  power_twi_disable();
  power_timer0_disable();
  //power_usart0_disable(); // this might be needed for serial communication
  Serial.begin(115200);

 byte* emittingPointer = &animation[frame][0];
 

  LOOP:
    while(PINB & 0b00001000); //wait for pin 11 (B3) to go low 
    
    OUTPUT_WAVE(emittingPointer, 0); WAIT_LIT();
    OUTPUT_WAVE(emittingPointer, 1); WAIT_MID();
    OUTPUT_WAVE(emittingPointer, 2); WAIT_MID();
    OUTPUT_WAVE(emittingPointer, 3); WAIT_MID();
    OUTPUT_WAVE(emittingPointer, 4); WAIT_MID();
    OUTPUT_WAVE(emittingPointer, 5); WAIT_MID();
    OUTPUT_WAVE(emittingPointer, 6); WAIT_MID();
    OUTPUT_WAVE(emittingPointer, 7); WAIT_MID();
    OUTPUT_WAVE(emittingPointer, 8); WAIT_LOT();
    OUTPUT_WAVE(emittingPointer, 9); WAIT_LOT();
    OUTPUT_WAVE(emittingPointer, 10); WAIT_LOT();
    OUTPUT_WAVE(emittingPointer, 11); WAIT_LOT();
    OUTPUT_WAVE(emittingPointer, 12); WAIT_LOT();
    OUTPUT_WAVE(emittingPointer, 13); WAIT_LOT();
    OUTPUT_WAVE(emittingPointer, 14); WAIT_LOT();
    OUTPUT_WAVE(emittingPointer, 15); WAIT_LOT();
    OUTPUT_WAVE(emittingPointer, 16); WAIT_LOT();
    OUTPUT_WAVE(emittingPointer, 17); WAIT_LOT();
    OUTPUT_WAVE(emittingPointer, 18); WAIT_LOT();
    OUTPUT_WAVE(emittingPointer, 19); WAIT_LOT();
    OUTPUT_WAVE(emittingPointer, 20); WAIT_LOT();
    OUTPUT_WAVE(emittingPointer, 21); WAIT_LOT();
    OUTPUT_WAVE(emittingPointer, 22); WAIT_LOT();
    OUTPUT_WAVE(emittingPointer, 23); 

  goto LOOP;
  
}

void loop(){}

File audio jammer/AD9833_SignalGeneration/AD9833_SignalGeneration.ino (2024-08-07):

const long BAUDRATE  = 115200;  // Baud rate of UART in bps


// Global Variables

// Defining the pins that we will be using on the Signal generator.
const int SG_fsyncPin = 2;
const int SG_CLK = 3;
const int SG_DATA = 4;
const int SG_POWER = 6;

// Hardcode the frequency to 25kHz // a) for testing but also because this is the center frequency of the transducers
const long FREQUENCY = 25000;


/* SG_WriteRegister

This function sends a 16 bit word to the signl generator by toggling specific control lines.

16-bit word: This means the data unit being processed or transmitted is 16 bits in length. 
This is the data we want to send, consisting of 16 bits.
6-bit word (dat) is sent bit by bit to the signal generator by toggling the clock (SG_CLK) and data (SG_DATA) pins
*/

const int wSine     = 0b0000000000000000;
const int wTriangle = 0b0000000000000010;
const int wSquare   = 0b0000000000101000;

void WriteRegister(word dat) {

  digitalWrite(SG_CLK, LOW); // setting clock pin low and then high to have a known state of the clock
  digitalWrite(SG_CLK, HIGH);

  digitalWrite(SG_fsyncPin, LOW); // setting the fsync pin to low, indicating the begin of data transfer 

  for (byte i = 0; i < 16; i++) { // loop through each bit in the 16 bit word 
    if (dat & 0x8000) // checks the most significant bit; if its 1 SG_data high otherwise low 
      digitalWrite(SG_DATA, HIGH); // Send each bit
    else
      digitalWrite(SG_DATA, LOW);
    dat = dat << 1; // Shifting this so the next bit is ready to be sent. 
    digitalWrite(SG_CLK, HIGH); // this line and next are creating a clock impulse => signaling to the generator to read the bit on the data pin
    digitalWrite(SG_CLK, LOW);
  }
  digitalWrite(SG_CLK, HIGH); // signal to end data transfer
  digitalWrite(SG_fsyncPin, HIGH); 
}


// Reset
void reset() {
  delay(100);
  WriteRegister(0x100);
  delay(100);
}

/*
Here we are setting the frequency and the waveform.
*/
// void set_frequency(long frequency) {
//   long fl = frequency * (0x10000000 / 25000000.0);
//   WriteRegister(0x2000); // Setting the wavetype
//   WriteRegister((int)(fl & 0x3FFF) | 0x4000);
//   WriteRegister((int)((fl & 0xFFFC000) >> 14) | 0x4000);
// }

void set_frequency(long frequency, int waveType) {
  long fl = frequency * (0x10000000 / 25000000.0);
  WriteRegister(0x2000 | waveType); // Setting the wavetype
  WriteRegister((int)(fl & 0x3FFF) | 0x4000);
  WriteRegister((int)((fl & 0xFFFC000) >> 14) | 0x4000);
}

// InitSigGen
//-----------------------------------------------------------------------------
void InitSigGen(void) {
  pinMode(SG_POWER, OUTPUT);
  digitalWrite(SG_POWER, HIGH);

  pinMode(SG_DATA, OUTPUT);
  pinMode(SG_CLK, OUTPUT);
  pinMode(SG_fsyncPin, OUTPUT);
  digitalWrite(SG_fsyncPin, HIGH);
  digitalWrite(SG_CLK, HIGH);
  reset();
  set_frequency(FREQUENCY, wSquare);
}

// Main functions 
void setup(){
  // Opening serial bud 
  Serial.begin(BAUDRATE);
  Serial.println("Generation started."); 

  // Initializing the Signal 
  InitSigGen(); 
}

void loop(){

  // Once the signal is initiated nothing has to happen anymore. 
}

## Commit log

2024-07-22 Coded simple sine wave output from an Arduino device for testing purposes
2024-07-23 Fixed error in sending waveform + added comments explaining code. Functional Code for sending 25kHz wave through Motor Driver to Transducers
    [transducer_sweep.ino]
2024-07-26 Modified code to switch between waveforms.
2024-08-10 Fixed code for square waves + sweep
    [L298N_waave_gen.ino]
2024-10-03 Added schematic
2024-11-01 Added PCB Design file
    [PCB_design.kicad_pcb, PCB_design.kicad_sch]
2024-11-02 Updated PCB Design
    [PCB_design.kicad_sch]
2024-11-06 Added ICs for battery charging and battery charging protection to implement with Boost Converter on PCB.
    [PCB_design.kicad_sch]
2024-11-07 Finished v0 of schematic
    [PCB_design.kicad_sch]
2024-11-09 Added most of the footprints and imported into PCB designer
    [PCB_design.kicad_pcb, PCB_design.kicad_sch]
2024-11-11 Progress on PCB, added different capacitors, continued routing
    [PCB_design.kicad_pcb, PCB_design.kicad_sch]
2024-11-12 Finished routing of PCB, v0
    [PCB_design.kicad_pcb, PCB_design.kicad_sch]
2024-11-12 Fixed routing to bottom layer
    [PCB_design.kicad_pcb]
2024-11-12 Removed GND to Bat- connection and rereouted
    [PCB_design.kicad_pcb, PCB_design.kicad_sch]
2024-11-12 Fixed issues surrounding wiring, Vss to Vs for 12V, CE actually enabled
    [PCB_design.kicad_pcb, PCB_design.kicad_sch]
2024-11-14 Fix errors on circuit schematic and reorder PCB layout
    [PCB_design.kicad_pcb, PCB_design.kicad_sch]
2024-11-17 Finished PCB design and outline, added interactive html design
    [PCB_design-B_Cu.gbr, PCB_design-B_Mask.gbr, PCB_design-B_Paste.gbp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]
2024-11-17 Added PCB design pdf
    [PCB_design.kicad_pcb, PCB_design.kicad_sch]
2024-11-17 Updated circuit schematic
2024-11-17 Actually added the new schematic
2024-11-17 Added design for in parallel transducer plug in
    [PCB_design.kicad_pcb, PCB_design.kicad_sch, Transducer_array.kicad_pcb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]
2024-11-25 Add new PCB Design
    [PCB-diffDC-B_Cu.gbr, PCB-diffDC-B_Mask.gbr, PCB-diffDC-B_Paste.gbp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]
